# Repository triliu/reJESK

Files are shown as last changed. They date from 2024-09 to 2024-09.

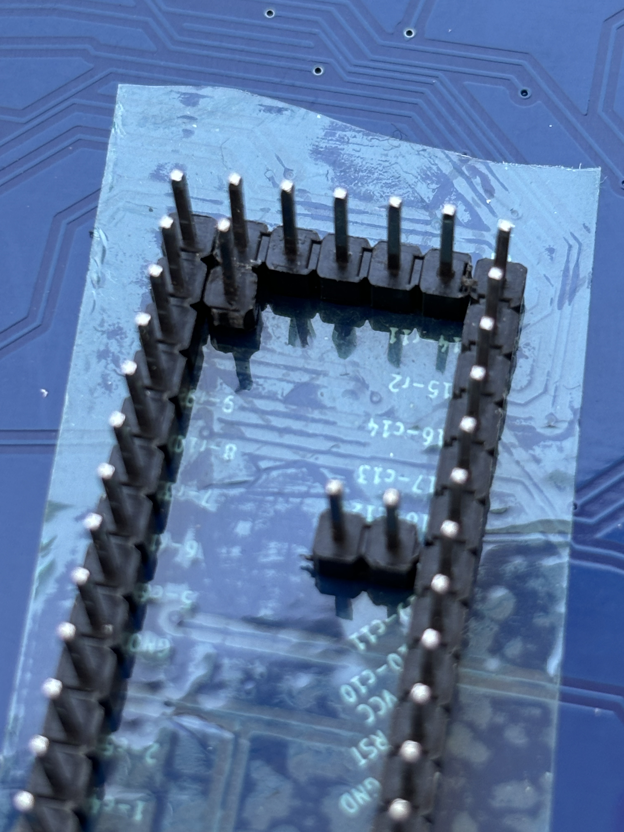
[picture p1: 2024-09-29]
Resources/Make11.jpg

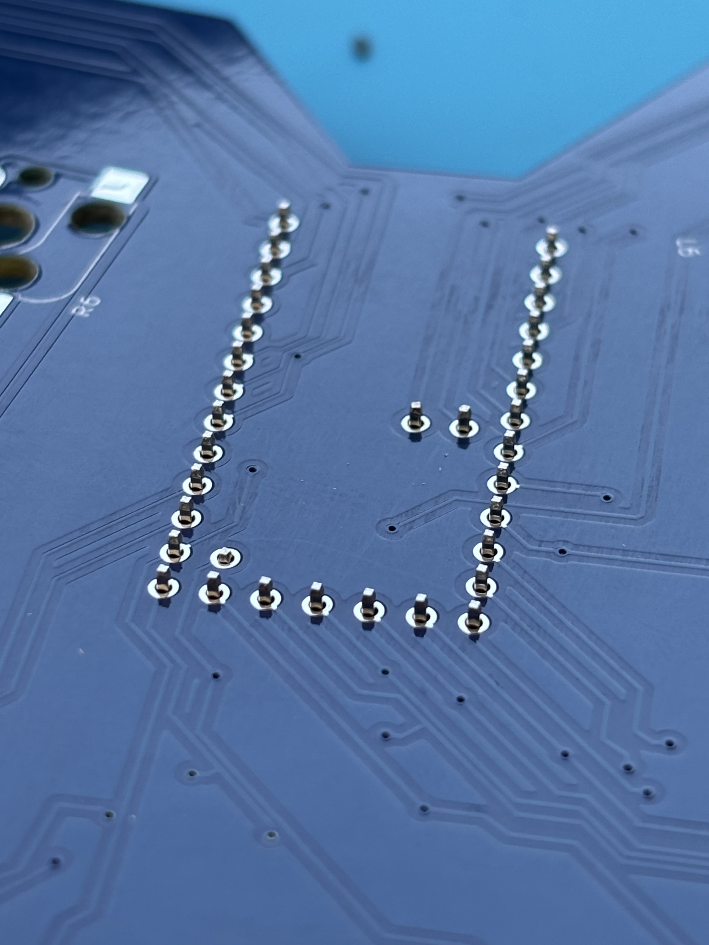
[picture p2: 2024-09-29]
Resources/Make12.jpg

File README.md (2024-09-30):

# reJESK
SideComplete1

The reJESK, a redox-inspired 70-switch ortholinear keyboard that uses a new diode-free design. 

FrontComplete

The diode-free design is easy for first-time keyboard makers, as it reduces the complexity and length of time to make your own board. This keyboard is part of the geometric diode-free keyboard project, which is creating keyboards with great key rollover characteristics without using diodes. Other keyboards released previously are the [Heawood42](https://github.com/triliu/Heawood42) (A 21*2-key split ortholinear board, with 21 keys per 14 GPIO) and the [JESK56](https://github.com/triliu/JESK56) (A 56-key monobody ortholinear board, with 56 keys using 28 GPIO). 

The diode-free design comes from a modification of the JESK graph, which was used in the [JESK56 keyboard](https://github.com/triliu/JESK56) to yield a 56-switch keyboard using 28 GPIO without diodes. This has been placed together with a design that is inspired by the [redox keyboard](https://github.com/mattdibi/redox-keyboard). The JESK graph was found by Exoo, Kolokolnikov, Janssen, Salamon; see their [arXiv paper](https://arxiv.org/abs/2307.07308) or [final publication](https://onlinelibrary.wiley.com/doi/10.1002/jgt.23146?af=R)

UnderneathComplete

This repo contains:
- PCB gerbers (production files) and kicad files (PCB design files). See below for easy print instructions. 
- QMK firmware
- 3D model case 
- (soon) build guide

reJESK

Many thanks to PCBway, who sponsered this project. You can easily print the reJESK keyboard using the project page on PCBway:

<a href="https://www.pcbway.com/project/shareproject/reJESK_keyboard_9f7bace9.html">PCB from PCBWay</a>

If you wish to modify and print the reJESK keyboard, consider using my affiliate link to help me out as I develop further boards: https://pcbway.com/g/oPKu26

"If you aren’t ready for reJESKtion, you aren’t ready for love.” – Marty Rubin

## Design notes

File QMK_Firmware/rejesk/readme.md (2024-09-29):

# Jesk56

triliu - Jesk56

Explainer

* Keyboard Maintainer: [Triliu](https://github.com/triliu) 
* Hardware Supported: Jesk56 v1
* Hardware Availability: (coming)

Place these files in .../qmk_firmware/keyboards/triliu/jesk56

To compile in QMK MYSY, run command:

    qmk compile -kb triliu/jesk56/rp2040 -km default

Make example for this keyboard (after setting up your build environment):

    make triliu/jesk56/rp2040:default

Flashing example for this keyboard:

    make triliu/jesk56/rp2040:default:flash

First time accessing the bootloader, you might have to hold the boot button and then press the reset button. 
Subsequently, enter bootloader by double-tapping reset button

See the [build environment setup](https://docs.qmk.fm/#/getting_started_build_tools) and the [make instructions](https://docs.qmk.fm/#/getting_started_make_guide) for more information. Brand new to QMK? Start with our [Complete Newbs Guide](https://docs.qmk.fm/#/newbs).

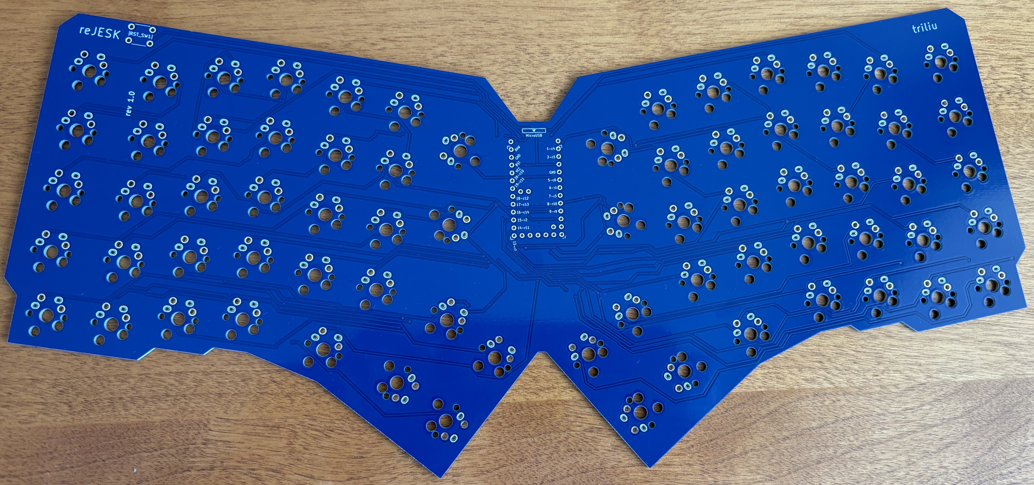
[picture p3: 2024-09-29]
Resources/FrontBoard.jpg

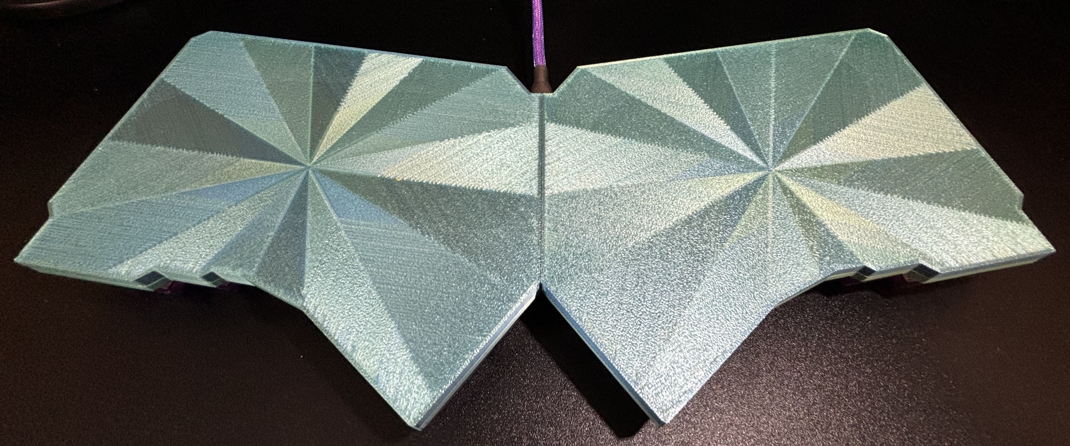
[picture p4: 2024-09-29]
Resources/UnderneathComplete.jpg

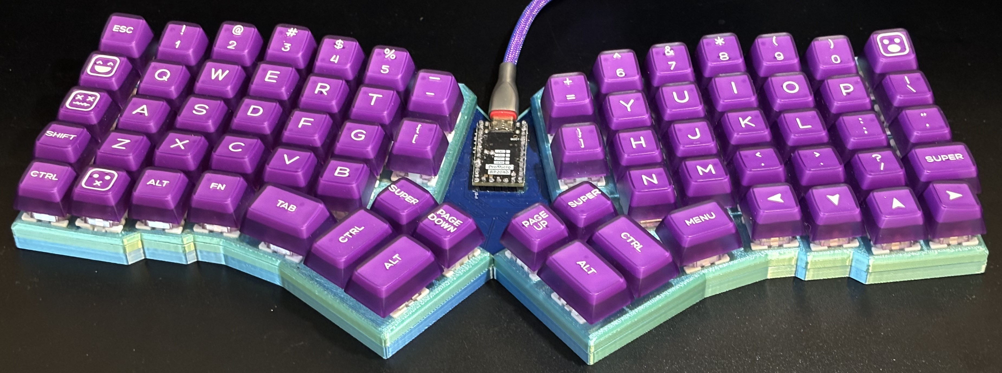
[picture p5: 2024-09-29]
Resources/FrontComplete.jpg

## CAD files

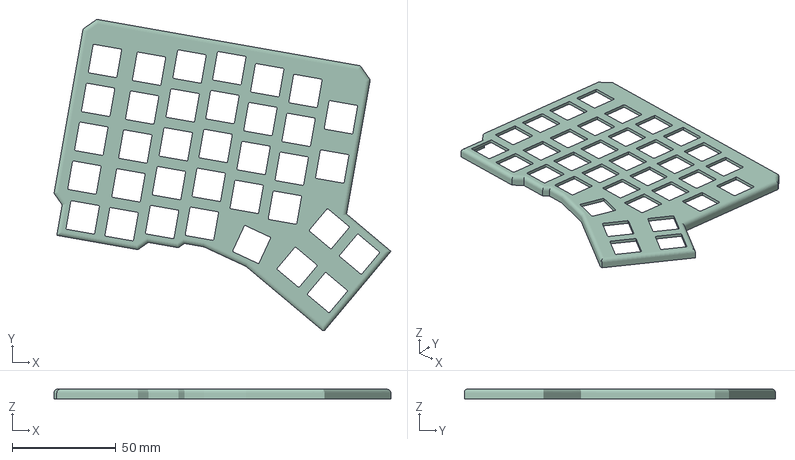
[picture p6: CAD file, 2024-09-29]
3d_print_files/reJESK_top_design_v2.3mf
162.6 x 150.3 x 5.00 mm

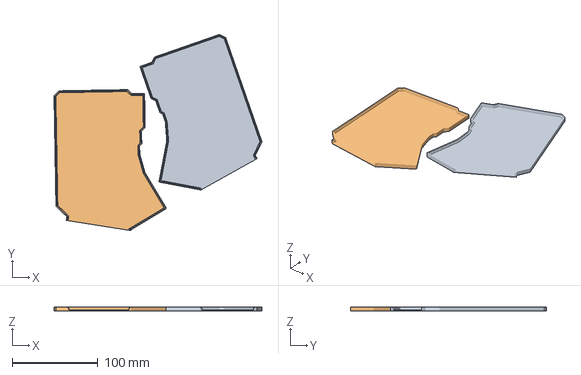
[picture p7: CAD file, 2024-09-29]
3d_print_files/reJESK_bottom_v2.2.3mf
243.3 x 229.4 x 5.20 mm

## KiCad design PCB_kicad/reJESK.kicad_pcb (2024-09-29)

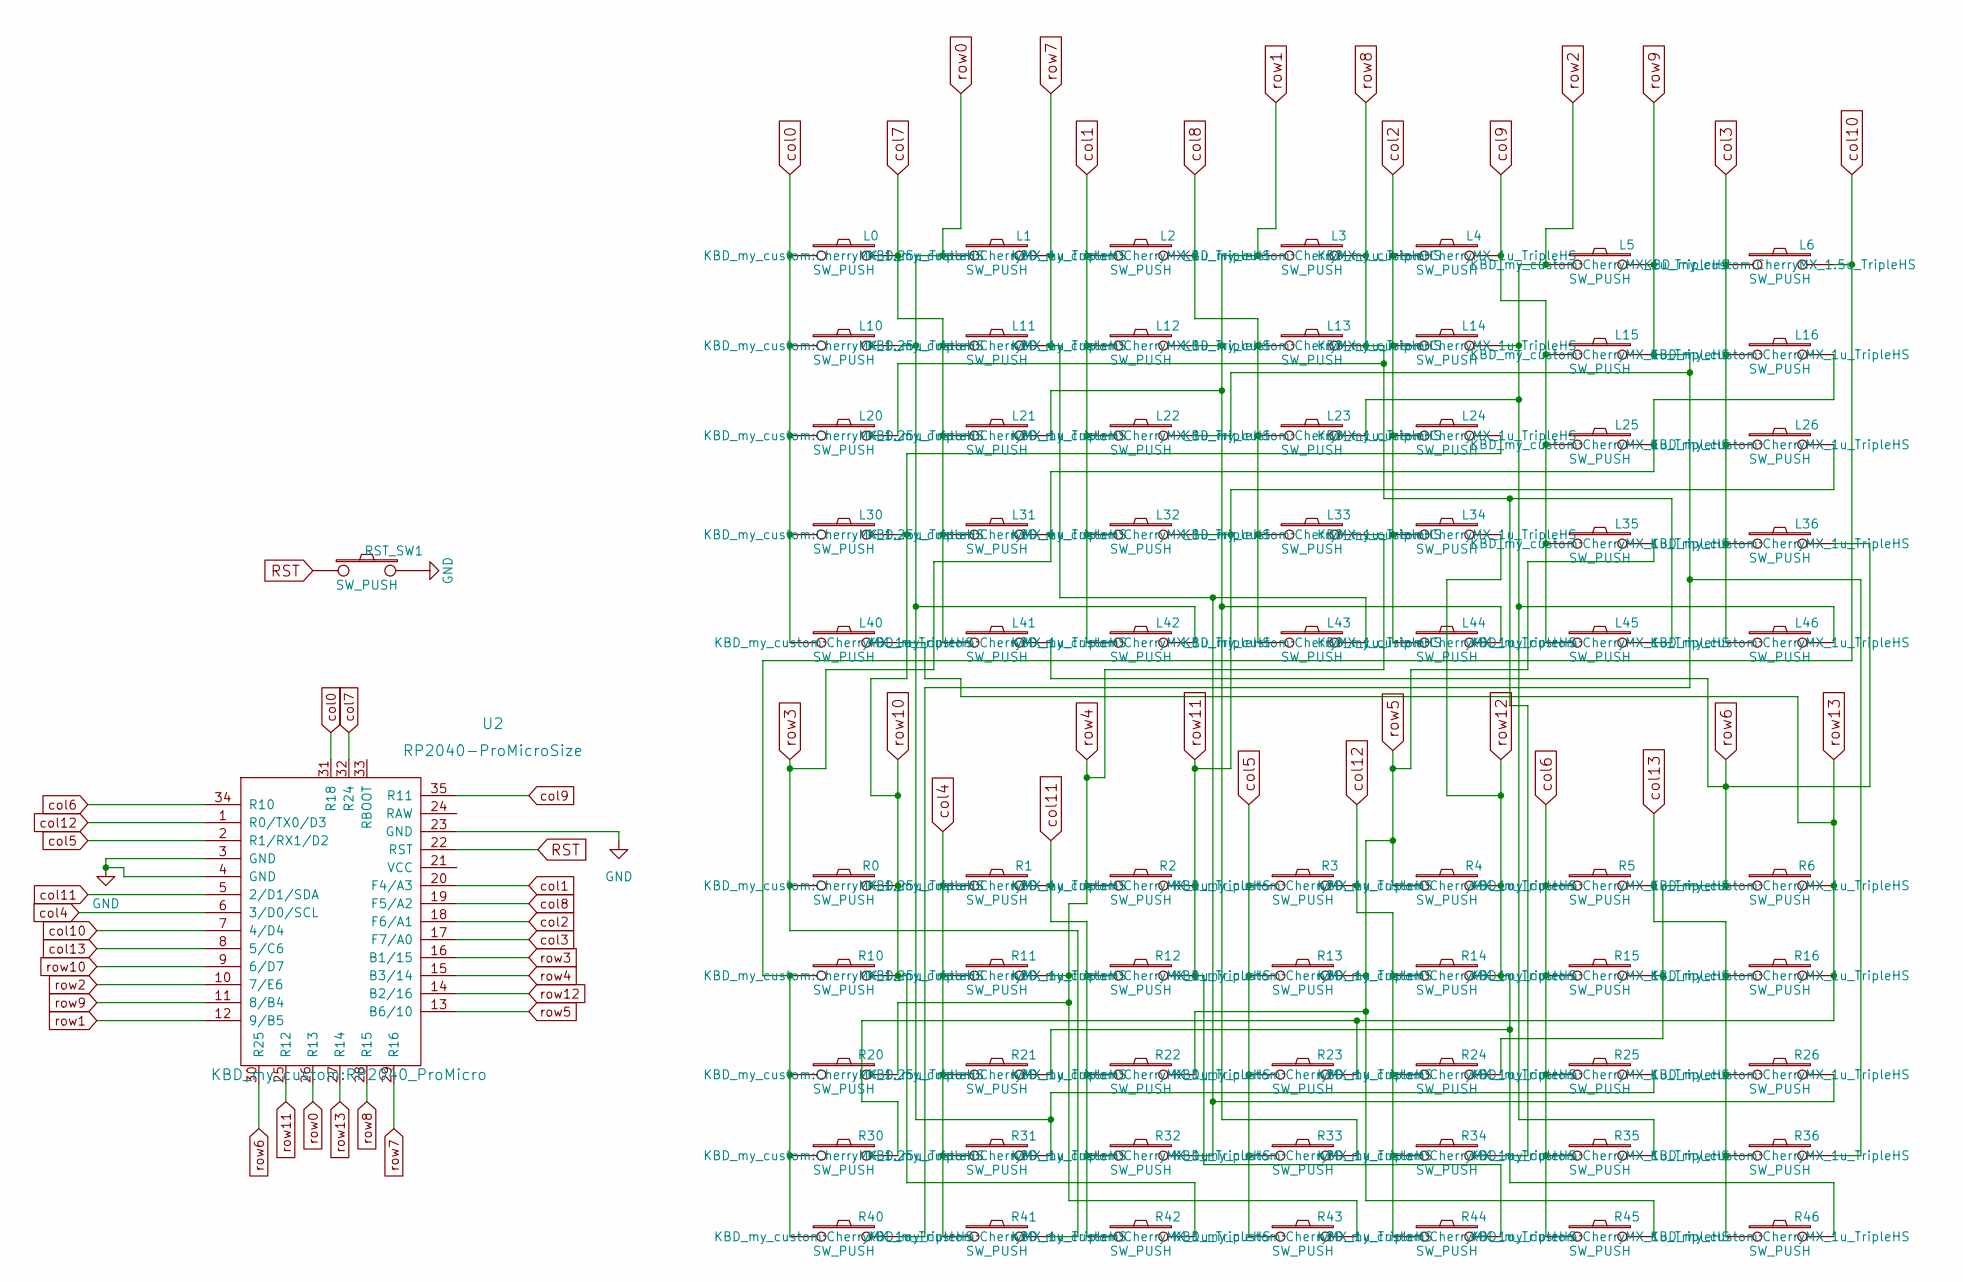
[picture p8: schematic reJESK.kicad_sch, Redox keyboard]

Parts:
L0, L10, L20, L30: SW_PUSH; CherryMX_1.25u_TripleHS
L1, L2, L3, L4, L5, L11, L12, L13, L14, L15, L16, L21, L22, L23, L24, L25, L26, L31, L32, L33, L34, L35, L36, L40, L41, L42, L43, L44, L45, L46: SW_PUSH; CherryMX_1u_TripleHS
L6: SW_PUSH; CherryMX_1.5u_TripleHS
R0, R10, R20, R30: SW_PUSH; CherryMX_1.25u_TripleHS
R1, R2, R3, R4, R5, R6, R11, R12, R13, R14, R15, R16, R21, R22, R23, R24, R25, R26, R31, R32, R33, R34, R35, R36, R40, R41, R42, R43, R44, R45, R46: SW_PUSH; CherryMX_1u_TripleHS
RST_SW1: SW_PUSH; SW_PUSH_6mm_h4.3mm
U2: RP2040-ProMicroSize; RP2040_ProMicro

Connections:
GND: RST_SW1.2, U2.3 (GND), U2.4 (GND), U2.23 (GND)
RST: RST_SW1.1, U2.22 (RST)
col0: L0.1, L10.1, L20.1, L30.1, L40.1, U2.31 (R18)
col1: L2.1, L12.1, L22.1, L32.1, L42.1, U2.20 (F4/A3)
col2: L4.1, L14.1, L24.1, L34.1, L44.1, U2.18 (F6/A1)
col3: L6.1, L16.1, L26.1, L36.1, L46.1, U2.17 (F7/A0)
col4: R1.1, R11.1, R21.1, R31.1, R41.1, U2.6 (3/D0/SCL)
col5: R3.1, R13.1, R23.1, R33.1, R43.1, U2.2 (R1/RX1/D2)
col6: R5.1, R15.1, R25.1, R35.1, R45.1, U2.34 (R10)
col7: L0.2, L11.1, L21.1, L31.1, L41.1, U2.32 (R24)
col8: L2.2, L13.1, L23.1, L33.1, L43.1, U2.19 (F5/A2)
col9: L4.2, L15.1, L25.1, L35.1, L45.1, U2.35 (R11)
col10: L6.2, R10.1, R20.1, R30.1, R40.1, U2.7 (4/D4)
col11: R1.2, R12.1, R22.1, R32.1, R42.1, U2.5 (2/D1/SDA)
col12: R3.2, R14.1, R24.1, R34.1, R44.1, U2.1 (R0/TX0/D3)
col13: R5.2, R16.1, R26.1, R36.1, R46.1, U2.8 (5/C6)
row0: L1.1, L10.2, L42.2, R25.2, R31.2, U2.26 (R13)
row1: L3.1, L12.2, L21.2, L44.2, R33.2, U2.12 (9/B5)
row2: L5.1, L14.2, L23.2, L46.2, R35.2, U2.10 (7/E6)
row3: L16.2, L25.2, L31.2, R0.1, R41.2, U2.16 (B1/15)
row4: L33.2, R2.1, R11.2, R20.2, R43.2, U2.15 (B3/14)
row5: L35.2, R4.1, R13.2, R22.2, R45.2, U2.13 (B6/10)
row6: L36.2, L41.2, R6.1, R15.2, R24.2, U2.30 (R25)
row7: L1.2, L11.2, L43.2, R26.2, R32.2, U2.29 (R16)
row8: L3.2, L13.2, L20.2, L45.2, R34.2, U2.28 (R15)
row9: L5.2, L15.2, L22.2, R36.2, R40.2, U2.11 (8/B4)
row10: L24.2, L30.2, R0.2, R10.2, R42.2, U2.9 (6/D7)
row11: L26.2, L32.2, R2.2, R12.2, R44.2, U2.25 (R12)
row12: L34.2, R4.2, R14.2, R21.2, R46.2, U2.14 (B2/16)
row13: L40.2, R6.2, R16.2, R23.2, R30.2, U2.27 (R14)

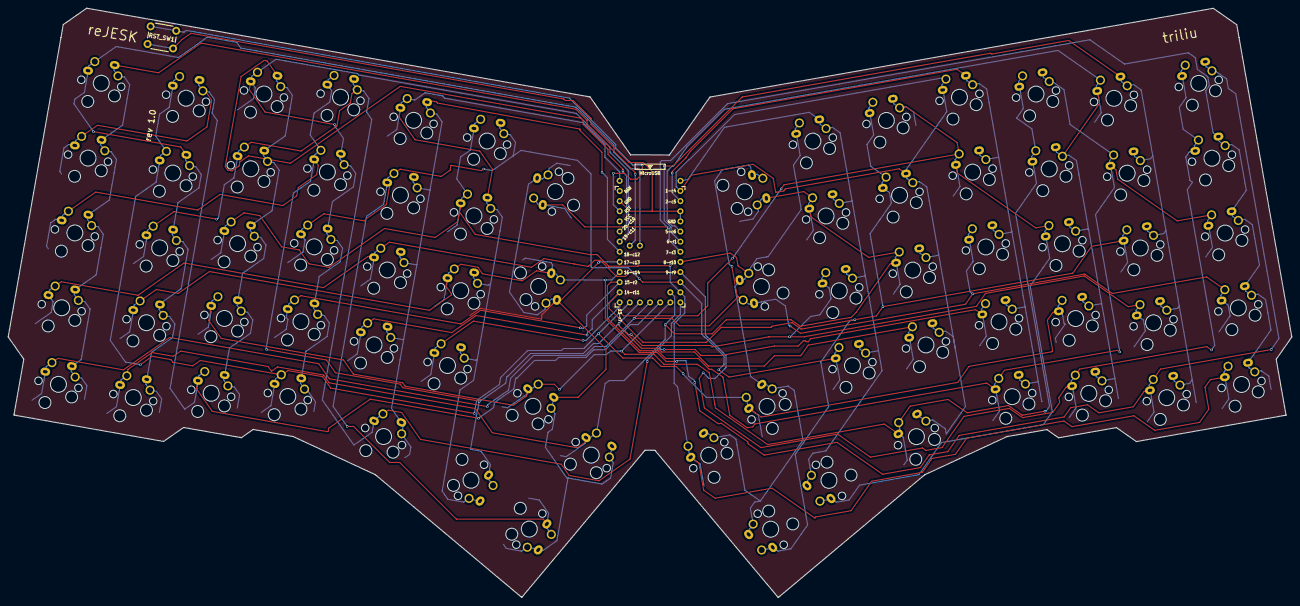
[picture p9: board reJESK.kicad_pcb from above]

Board: 2 copper layers, 321.8 x 147.7 mm, 72 parts (0 on the bottom side), 30 nets.

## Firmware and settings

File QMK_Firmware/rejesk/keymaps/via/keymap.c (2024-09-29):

// Copyright 2024 Trent G. Marbach (https://github.com/triliu)
// SPDX-License-Identifier: GPL-2.0-or-later

#include QMK_KEYBOARD_H

enum layers {
    _QWERTY,
    _LOWER,
    _RAISE,
    _ADJUST
};

#define RAISE MO(_RAISE)
#define LOWER MO(_LOWER)

const uint16_t PROGMEM keymaps[][MATRIX_ROWS][MATRIX_COLS] = {
 
/* QWERTY
 * ,-----------------------------------------.                    ,-----------------------------------------.
 * | ESC  |   1  |   2  |   3  |   4  |   5  |                    |   6  |   7  |   8  |   9  |   0  |  `   |
 * |------+------+------+------+------+------|                    |------+------+------+------+------+------|
 * | Tab  |   Q  |   W  |   E  |   R  |   T  |                    |   Y  |   U  |   I  |   O  |   P  |  -   |
 * |------+------+------+------+------+------|                    |------+------+------+------+------+------|
 * |LCTRL |   A  |   S  |   D  |   F  |   G  |-------.    ,-------|   H  |   J  |   K  |   L  |   ;  |  '   |
 * |------+------+------+------+------+------|   [   |    |    ]  |------+------+------+------+------+------|
 * |LShift|   Z  |   X  |   C  |   V  |   B  |-------|    |-------|   N  |   M  |   ,  |   .  |   /  |RShift|
 * `-----------------------------------------/       /     \      \-----------------------------------------'
 *                   | LAlt | LGUI |LOWER | /Space  /       \Enter \  |RAISE |BackSP| RGUI |
 *                   |      |      |      |/       /         \      \ |      |      |      |
 *                   `----------------------------'           '------''--------------------'
 */

 [_QWERTY] = LAYOUT(
  KC_ESC,   KC_1,   KC_2,    KC_3,    KC_4,    KC_5,                     KC_6,    KC_7,    KC_8,    KC_9,    KC_0,    KC_GRV,
  KC_TAB,   KC_Q,   KC_W,    KC_E,    KC_R,    KC_T,                     KC_Y,    KC_U,    KC_I,    KC_O,    KC_P,    KC_MINS,
  KC_LCTL,  KC_A,   KC_S,    KC_D,    KC_F,    KC_G,                     KC_H,    KC_J,    KC_K,    KC_L,    KC_SCLN, KC_QUOT,
  KC_LSFT,  KC_Z,   KC_X,    KC_C,    KC_V,    KC_B, KC_LBRC,  KC_RBRC,  KC_N,    KC_M,    KC_COMM, KC_DOT,  KC_SLSH,  KC_RSFT,
                          KC_LALT,    KC_LGUI, LOWER, KC_SPC,  KC_ENT,   RAISE,   KC_BSPC, KC_RGUI
),
/* LOWER
 * ,-----------------------------------------.                    ,-----------------------------------------.
 * |      |      |      |      |      |      |                    |      |      |      |      |      |      |
 * |------+------+------+------+------+------|                    |------+------+------+------+------+------|
 * |  F1  |  F2  |  F3  |  F4  |  F5  |  F6  |                    |  F7  |  F8  |  F9  | F10  | F11  | F12  |
 * |------+------+------+------+------+------|                    |------+------+------+------+------+------|
 * |   `  |   !  |   @  |   #  |   $  |   %  |-------.    ,-------|   ^  |   &  |   *  |   (  |   )  |   -  |
 * |------+------+------+------+------+------|   [   |    |    ]  |------+------+------+------+------+------|
 * |      |      |      |      |      |      |-------|    |-------|      |   _  |   +  |   {  |   }  |   |  |
 * `-----------------------------------------/       /     \      \-----------------------------------------'
 *                   | LAlt | LGUI |LOWER | /Space  /       \Enter \  |RAISE |BackSP| RGUI |
 *                   |      |      |      |/       /         \      \ |      |      |      |
 *                   `----------------------------'           '------''--------------------'
 */
[_LOWER] = LAYOUT(
  _______, _______, _______, _______, _______, _______,                   _______, _______, _______,_______, _______, _______,
  KC_F1,   KC_F2,   KC_F3,   KC_F4,   KC_F5,   KC_F6,                     KC_F7,   KC_F8,   KC_F9,   KC_F10,  KC_F11,  KC_F12,
  KC_GRV, KC_EXLM, KC_AT,   KC_HASH, KC_DLR,  KC_PERC,                   KC_CIRC, KC_AMPR, KC_ASTR, KC_LPRN, KC_RPRN, KC_TILD,
  _______, _______, _______, _______, _______, _______, _______, _______, XXXXXXX, KC_UNDS, KC_PLUS, KC_LCBR, KC_RCBR, KC_PIPE,
                             _______, _______, _______, _______, _______,  _______, _______, _______
),
/* RAISE
 * ,-----------------------------------------.                    ,-----------------------------------------.
 * |MOD   | MODR |  S+  |  S-  |  B+  |  B-  |                    |      |      |      |      |      |      |
 * |------+------+------+------+------+------|                    |------+------+------+------+------+------|
 * |   `  |   1  |   2  |   3  |   4  |   5  |                    |   6  |   7  |   8  |   9  |   0  |      |
 * |------+------+------+------+------+------|                    |------+------+------+------+------+------|
 * |  F1  |  F2  |  F3  |  F4  |  F5  |  F6  |-------.    ,-------|      | Left | Down |  Up  |Right |      |
 * |------+------+------+------+------+------|RGB_TOG|    |    ]  |------+------+------+------+------+------|
 * |  F7  |  F8  |  F9  | F10  | F11  | F12  |-------|    |-------|   +  |   -  |   =  |   [  |   ]  |   \  |
 * `-----------------------------------------/       /     \      \-----------------------------------------'
 *                   | LAlt | LGUI |LOWER | /Space  /       \Enter \  |RAISE |BackSP| RGUI |
 *                   |      |      |      |/       /         \      \ |      |      |      |
 *                   `----------------------------'           '------''--------------------'
 */
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
